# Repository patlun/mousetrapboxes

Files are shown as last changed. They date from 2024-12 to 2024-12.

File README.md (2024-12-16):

# Mouse trap boxes
openscad code for mouse trap boxes

When using mouse traps I have missed some mice because they have been able to access the trap from behind and even if the trap have triggered they have come away with the bait. I created a small box to prevent this and to force the mouse to access the bait in a optimal way for the trap.

The box also gives some protection from snow and ice if you place the trap outdoors

The box have two parts called bottom and top as shown below

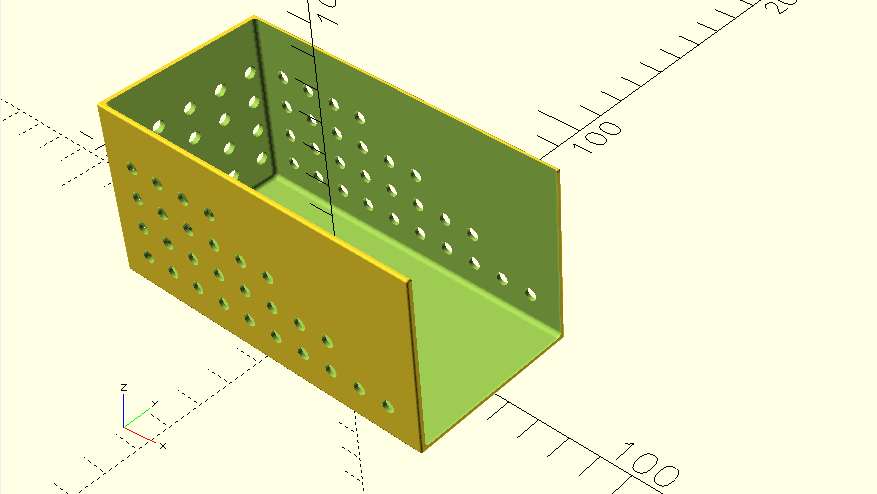
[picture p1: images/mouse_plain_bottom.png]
Bottom part

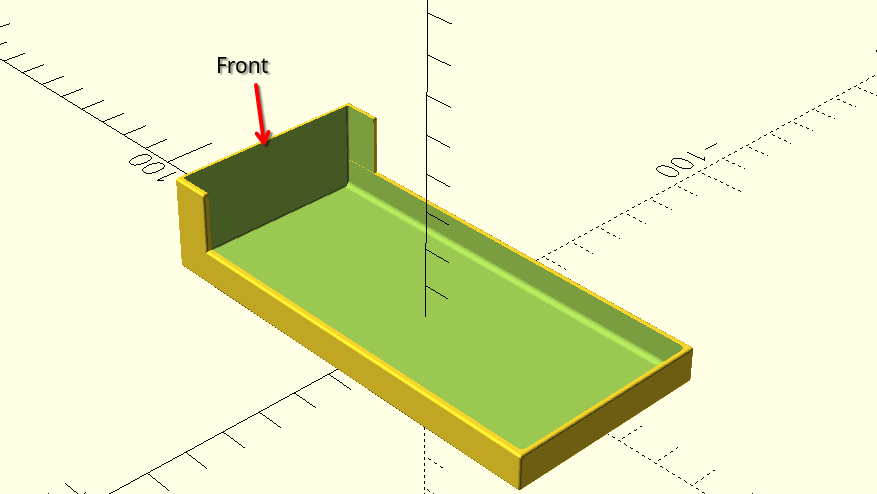
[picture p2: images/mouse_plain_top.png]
Top part


The box above is created with mouse.scad. There is also a modified version that have a simple mechanism for holding or locking the top in place called mouse_w_lock.scad.

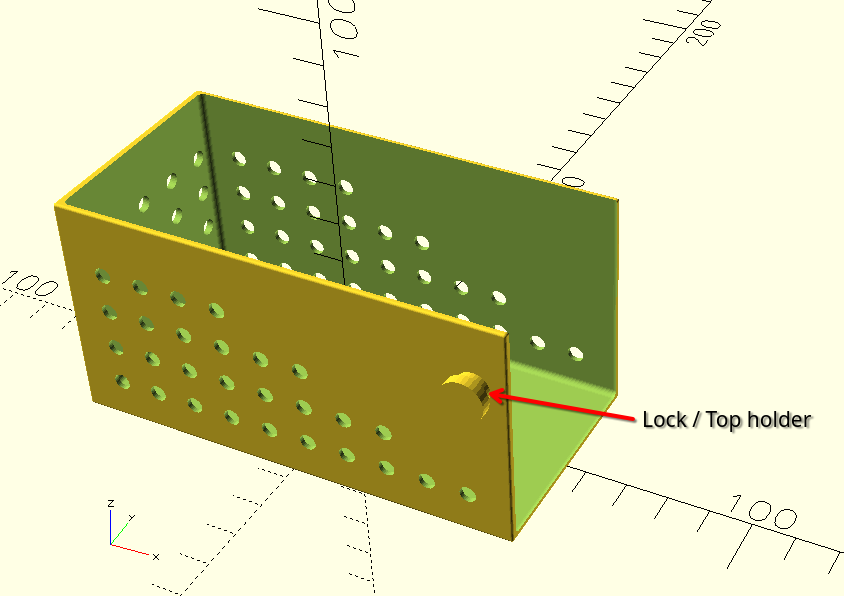
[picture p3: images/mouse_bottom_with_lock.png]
Bottom part with lock


# Usage

## Prerequistes
- Actual version of [Openscad](https://openscad.org/), I use the development Snapshots
- You need to install [BOSL2](https://github.com/BelfrySCAD/BOSL2/wiki) 

## Execution
Open the file mouse.scad in Openscad and either edit directly or use the Customizer. The defaults gives a box for a standard Swedish mouse trap. 

# Scad files

There is some files using a common file (mousetrap_common.scad, the provided files gives the ability to create bottom and top for normal Swedish mouse traps and Mjölner mouse traps with and with out locking mechanism.

- [Small mouse trap top and bottom](src/mouse.scad)
- [Small mouse trap top and bottom with locking](src/mouse_w_lock.scad)
- [Mjölner mouse trap top and bottom](src/Mjölner.scad)
- [Mjölner mouse trap top and bottom with locking](src/Mjölner_w_lock.scad)

You can use the customier to set the measurerments you need.

# Stl

There is stl files for the top and bottom with and without locking mechanism in the stl directory

# Printing

I have used Sunlu PETG for printing as I use my boxes outdoors. I sliced with Orcaslicer using
- Creality Generic PETG settings
- 0.3mm layer height
- Manual tree support for the locks to save material, auto support creates supports for the holes in the sides.

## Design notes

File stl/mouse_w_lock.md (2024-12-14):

# Example files for mouse with lock

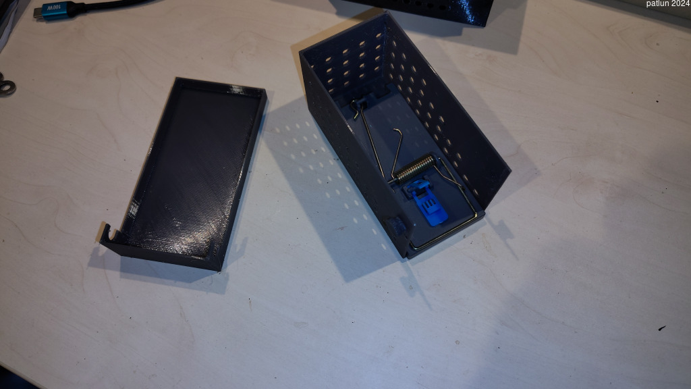
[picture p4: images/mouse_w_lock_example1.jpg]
Open box


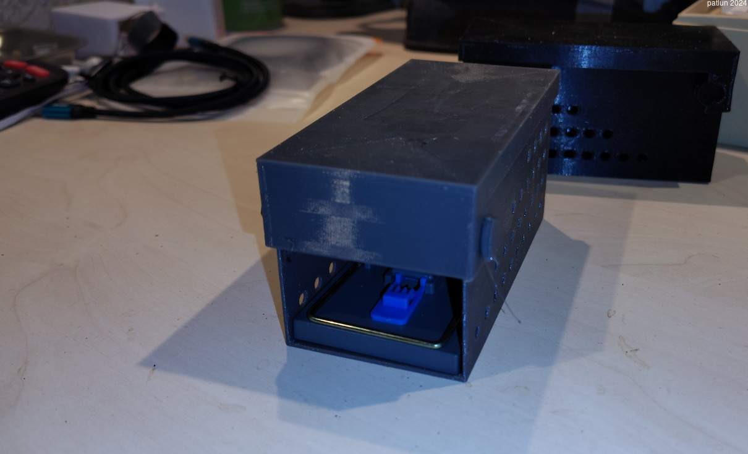
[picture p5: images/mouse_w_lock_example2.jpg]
Closed box with mouse trap


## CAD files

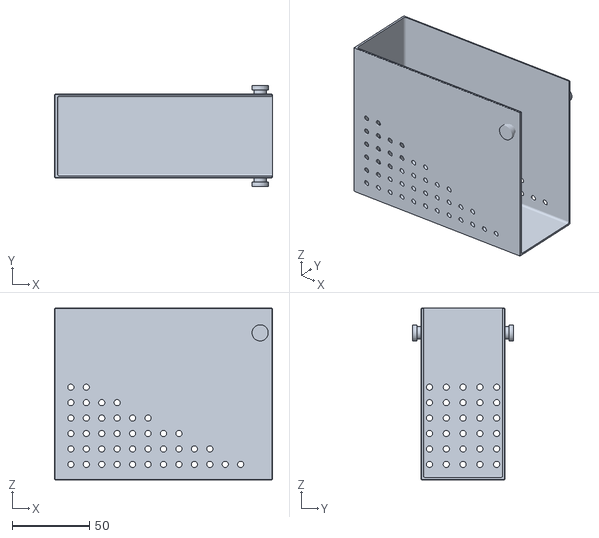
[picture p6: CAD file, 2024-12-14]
stl/Mjölner_w_lock_bottom.stl
141.2 x 65.2 x 111.2

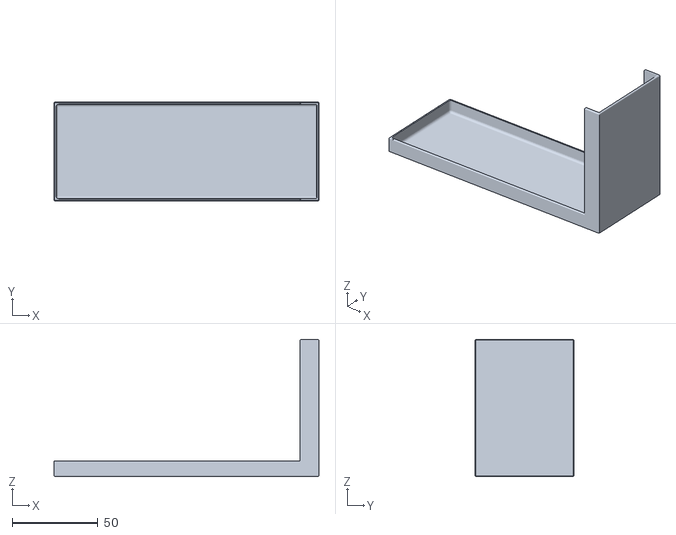
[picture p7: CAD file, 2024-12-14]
stl/Mjölner_top.stl
154.7 x 57.6 x 80.0

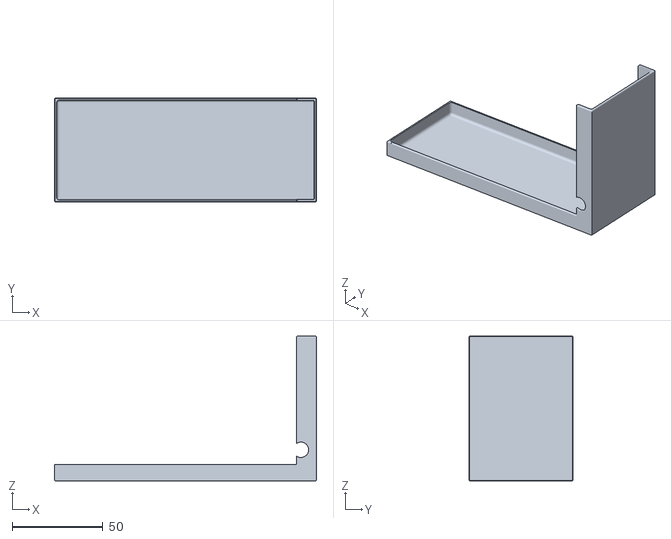
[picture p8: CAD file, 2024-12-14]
stl/Mjölner_w_lock_top.stl
144.7 x 57.6 x 80.0

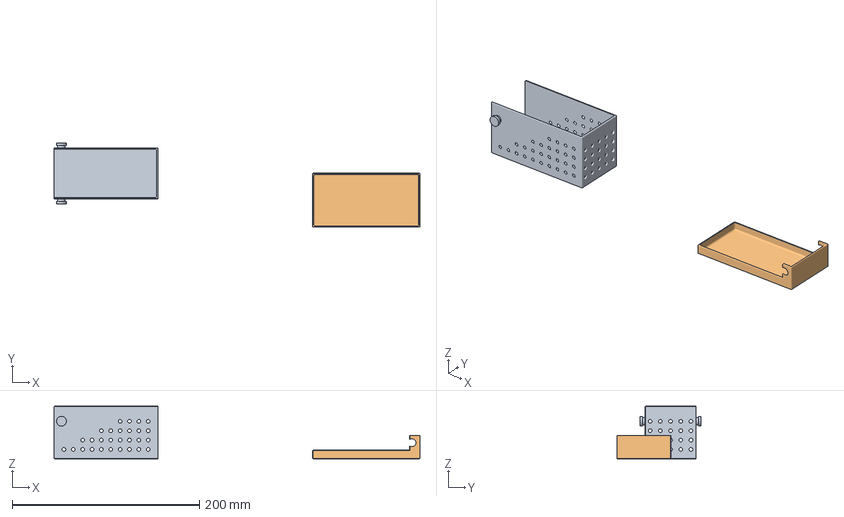
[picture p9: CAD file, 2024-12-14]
stl/mouse_top.3mf
390.8 x 90.0 x 56.2 mm
mouse_w_lock_bottom.stl
mouse_w_lock_top.stl

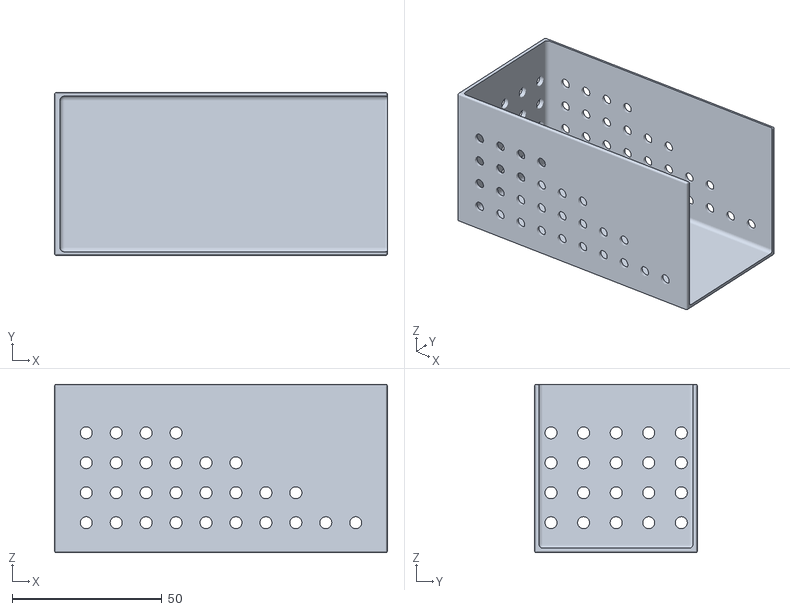
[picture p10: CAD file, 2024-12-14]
stl/mouse_bottom.stl
111.2 x 54.4 x 56.2

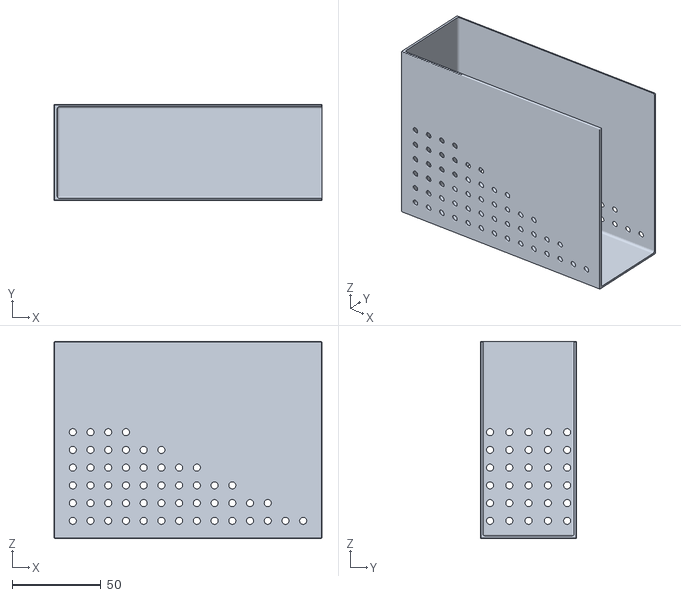
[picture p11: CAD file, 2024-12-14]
stl/Mjölner_bottom.stl
151.2 x 54.4 x 111.2

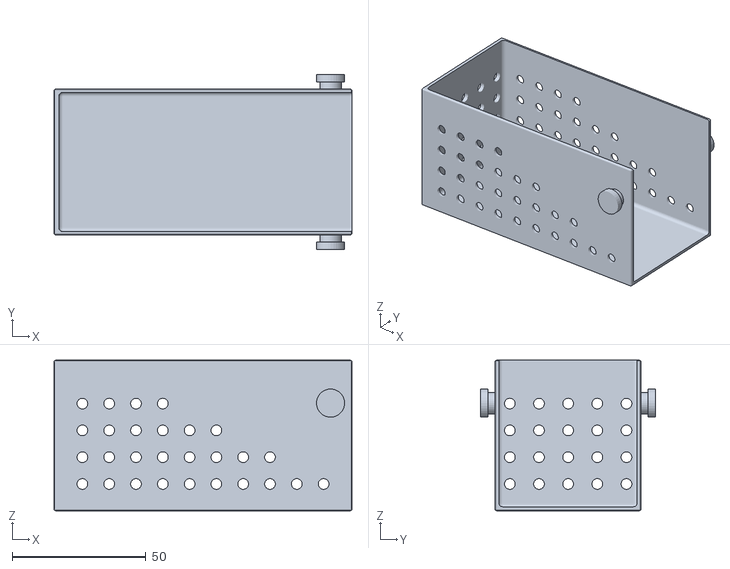
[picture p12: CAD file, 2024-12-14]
stl/mouse_w_lock_bottom.stl
111.2 x 65.2 x 56.2

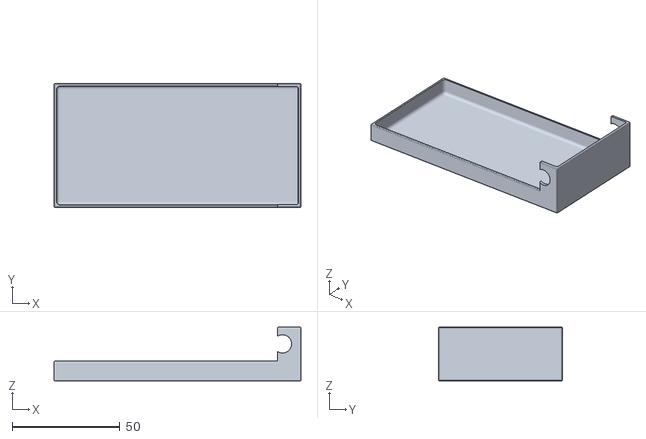
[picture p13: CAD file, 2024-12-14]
stl/mouse_w_lock_top.stl
114.7 x 57.6 x 25.0

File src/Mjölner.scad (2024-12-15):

include <mousetrap_common.scad>
$fn=32;

// Generate a plain top or bottom, change variables to get the result you like
// This file creates a box for the Mjölner mouse trap

// What to generate - Valid values: bottom, top
generate = "bottom"; 

// measurements inside of box

// Length in millimeter
innerlength=150;
//Width  in millimeter
innerwidth=52;
// Height in millimeter
innerheight=110;

// The number of hole rows in bottom part
number_of_hole_rows=6;
// Number of holes at lowest row
number_of_holes_bottom_row=14; 

if (generate == "bottom")
    bottom (innerlength, innerwidth, innerheight, number_of_hole_rows, number_of_holes_bottom_row);
else if (generate == "top")
    top(innerlength, innerwidth, innerheight);
else
  echo ("Need to give some input");
  

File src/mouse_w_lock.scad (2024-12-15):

include <mousetrap_common.scad>
$fn=32;


// Generate top or bottom with a simple locking mechanism to hold the top in place, change variables to get the result you like

// What to generate - Valid values: bottom, top
generate = "bottom"; 

// measurements inside of box

// Length in millimeter
innerlength=110;
//Width  in millimeter
innerwidth=52;
// Height in millimeter
innerheight=55;

// The number of hole rows in bottom part
number_of_hole_rows=4;
// Number of holes at lowest row
number_of_holes_bottom_row=10; 

if (generate == "bottom")
    bottom_w_pins (innerlength, innerwidth, innerheight, number_of_hole_rows, number_of_holes_bottom_row);
else if (generate == "top")
    top_for_pins(innerlength, innerwidth, innerheight);
else
  echo ("Need to give some input");
  

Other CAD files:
src/Mjölner_w_lock.scad
src/mouse.scad
src/mousetrap_common.scad
stl/mouse_top.stl

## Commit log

2024-12-14 Start docuemntation and adds images
    [mouse.scad, mouse_w_lock.scad, mousetrap_common.scad]
2024-12-14 Updates doc, added stl files, added scad files and License
    [mouse.scad, mouse_bottom.stl, mouse_top.stl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]
2024-12-14 Change how lockplacementZ is computed, fix width of top
    [mousetrap_common.scad]
2024-12-14 More fixes of top part, width and length
    [mousetrap_common.scad]
2024-12-14 Regenerate stls after refactoring and bug fixes
    [mouse_w_lock_bottom.stl, mouse_w_lock_top.stl]
2024-12-15 Remove include of BOSL2 as that is done in common.
    [mouse.scad, mouse_w_lock.scad]
2024-12-15 Add scad files for Mjölner brand
    [Mjölner.scad, Mjölner_w_lock.scad]
2024-12-15 Fix spelling
    [Mjölner.scad, Mjölner_w_lock.scad, mouse.scad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]
